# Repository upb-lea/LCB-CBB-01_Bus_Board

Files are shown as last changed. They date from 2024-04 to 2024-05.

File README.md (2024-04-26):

# Bus board LCB-CBB-01 for the LEA control board

This is the dock extension board for the LEA control board LCB-CCB-01. Please refer to the [LCB-CCB-01 repository](https://github.com/upb-lea/LCB-CCB-01_LEA_Control_Board) for a PCB and project overview.

Note, that you also need to install the `LEA KiCad Library` to view this PCB in this repository. To do this, follow the instructions mentioned [here](https://github.com/upb-lea/LCB-CCB-01_LEA_Control_Board/blob/main/README.md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).

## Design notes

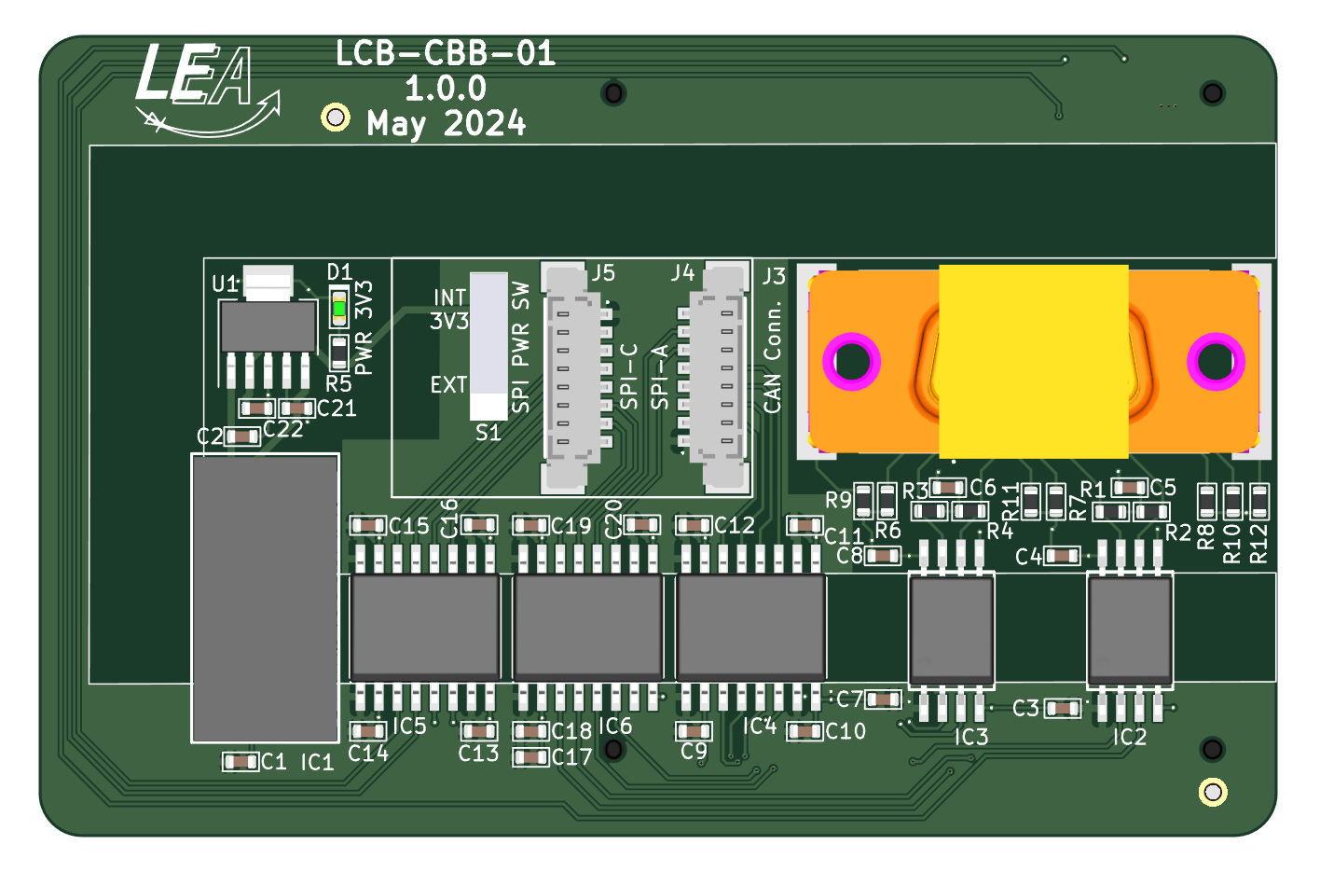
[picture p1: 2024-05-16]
LCB-CBB-01/LCB-CBB-01.png

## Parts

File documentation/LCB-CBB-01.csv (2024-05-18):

Source: | /home/nikolasf/Dokumente/01_git/70_PCBs/LCB-CBB-01_Bus_Board/LCB-CBB-01/LCB-CBB-01.kicad_sch
Date: | 2024-05-18T19:11:30+0200
Tool: | Eeschema 8.0.2
Generator: | /usr/share/kicad/plugins/bom_csv_grouped_by_value.py
Component Count: | 50
Collated Components:
Item | Qty | Reference(s) | Value | LibPart | Footprint | Datasheet | DNP | Datasheet | Description | Footprint | Manufacturer | Mfr. No | Mouser No | Sim.Enable | manf# | mouser#
1 | 2 | ACCESSORY1, ACCESSORY2 | ACCESSORY_BusBoard_SPI_Cable | LEA_SymbolLibrary:ACCESSORY_BusBoard_SPI_Cable |  | https://www.molex.com/en-us/products/part-detail/151340805 |  | https://www.molex.com/en-us/products/part-detail/151340805 |  |  | Molex |  |  |  | 15134-0805 | 538-15134-0805
2 | 12 | C1, C2, C3, C4, C7, C8, C10, C11, C14, C15, C18, C19 | 100n | LEA_SymbolLibrary:C_0603_100n_X5R_10P__50V | LEA_FootprintLibrary:C_0603 |  |  |  | Capacitor 0603 | LEA_FootprintLibrary:C_0603 | TDK |  |  |  | C1608X5R1H104K | 810-C1608X5R1H104K
3 | 2 | C5, C6 | 47n | LEA_SymbolLibrary:C_0603__47n_X7R_10P__50V | LEA_FootprintLibrary:C_0603 | https://www.mouser.de/datasheet/2/281/1/GCM188R71H473KA55_01A-3144223.pdf |  | https://www.mouser.de/datasheet/2/281/1/GCM188R71H473KA55_01A-3144223.pdf | Capacitor 0603 | LEA_FootprintLibrary:C_0603 | murata |  |  |  | GCM188R71H473K55D | 81-GCM188R71H473K55D
4 | 6 | C9, C12, C13, C16, C17, C20 | 2u2 | LEA_SymbolLibrary:C_0603__2u2_X5R_10P__35V | LEA_FootprintLibrary:C_0603 |  |  |  | Capacitor 0603 | LEA_FootprintLibrary:C_0603 | TDK |  |  |  | C1608X5R1V225K | 810-C1608X5R1V225K
5 | 1 | C21 | 10n | LEA_SymbolLibrary:C_0603__10n_X7R_10P__50V | LEA_FootprintLibrary:C_0603 |  |  |  | Capacitor 0603 | LEA_FootprintLibrary:C_0603 | TDK |  |  |  | CGA3E2X7R1H103K | 810-CGA3E2X7R1H103K
6 | 1 | C22 | 10u | LEA_SymbolLibrary:C_0603__10u_X5R_10P__25V | LEA_FootprintLibrary:C_0603 |  |  |  | Capacitor 0603 | LEA_FootprintLibrary:C_0603 | Murata |  |  |  | GRM188R61E106KA3D | 81-GRM188R61E106KA3D
7 | 1 | D1 | 2mA | LEA_SymbolLibrary:LED_0603_G_2mA_APTD1608LCGCK | LEA_FootprintLibrary:LED_0603_G | https://www.mouser.de/datasheet/2/216/APTD1608LCGCK-1102124.pdf |  | https://www.mouser.de/datasheet/2/216/APTD1608LCGCK-1102124.pdf | LED 0603, Green, If 2mA, Vf 1.9V | LEA_FootprintLibrary:LED_0603_G | Kingbright |  |  |  | APTD1608LCGCK | 604-APTD1608LCGCK
8 | 1 | IC1 | MEJ2S0305SC | LEA_SymbolLibrary:DCDC_3V3_5V0_MEJ2S0305SC | LEA_FootprintLibrary:SIP-7_Murata_MEJ1S0305SC | https://eu.mouser.com/datasheet/2/281/1/kdc_mej2-2941219.pdf |  | https://eu.mouser.com/datasheet/2/281/1/kdc_mej2-2941219.pdf | Isolated DC-DC Converter. 3.3Vin, 5Vout, 2W | LEA_FootprintLibrary:SIP-7_Murata_MEJ1S0305SC | Murata |  |  |  | MEJ2S0305SC | 580-MEJ2S0305SC
9 | 2 | IC2, IC3 | ISO1042QDWVRQ1 | LEA_SymbolLibrary:ISO_ISO1042QDWVRQ1 | LEA_FootprintLibrary:SOIC127P1150X280-8N | http://www.ti.com/lit/gpn/ISO1042-Q1 |  | http://www.ti.com/lit/gpn/ISO1042-Q1 | Isolated CAN transceiver, Automotive, 70-V bus fault protection and flexible data rate | LEA_FootprintLibrary:SOIC127P1150X280-8N | Texas Instruments |  |  |  | ISO1042QDWVRQ1 | 595-ISO1042QDWVRQ1
10 | 2 | IC4, IC5 | ISO7741FQDWQ1 | LEA_SymbolLibrary:ISO_ISO7741FQDWQ1 | LEA_FootprintLibrary:SOIC127P1030X265-16N | http://www.ti.com/lit/gpn/iso7741-q1 |  | http://www.ti.com/lit/gpn/iso7741-q1 | Automotive, High Speed, Robust EMC Quad-Channel Digital Isolators | LEA_FootprintLibrary:SOIC127P1030X265-16N | Texas Instruments |  |  |  | ISO7741FQDWQ1 | 595-ISO7741FQDWQ1
11 | 1 | IC6 | ISO_ISO7740FQDWQ1 | LEA_SymbolLibrary:ISO_ISO7740FQDWQ1 | LEA_FootprintLibrary:SOIC127P1030X265-16N | https://www.ti.com/lit/ds/symlink/iso7741-q1.pdf?ts=1637972753620 |  | https://www.ti.com/lit/ds/symlink/iso7741-q1.pdf?ts=1637972753620 | ISO774x-Q1 Automotive, High-Speed, Reinforced Quad-Channel Digital Isolators | LEA_FootprintLibrary:SOIC127P1030X265-16N | Texas Instruments |  |  |  | ISO7740FQDWQ1 | 595-ISO7740FQDWQ1
12 | 2 | J1, J2 | ERM5-075-05.0-L-DV-K-TR | LEA_SymbolLibrary:Conn_ERM5-075-05.0-L-DV-K-TR | LEA_FootprintLibrary:ERM5-075-05.0-L-DV | https://suddendocs.samtec.com/prints/erm5-xxx-xx.x-dv-xx-tr-footprint.pdf |  | https://suddendocs.samtec.com/prints/erm5-xxx-xx.x-dv-xx-tr-footprint.pdf | Board to Board & Mezzanine Connectors 0.50 mm Edge Rate Rugged High Speed Terminal | LEA_FootprintLibrary:ERM5-075-05.0-L-DV | Samtec | ERM5-075-05.0-L-DV-K-TR | 200-ERM5075050LDVKTR | 0 | ERM5-075-05.0-L-DV-K-TR | 200-ERM5075050LDVKTR
13 | 1 | J3 | 09551156612741 | LEA_SymbolLibrary:Conn_sub-D_09551156612741 | LEA_FootprintLibrary:Conn_Sub-D_09551156612741 | https://b2b.harting.com/files/download/PRD/PDF_TS/0955115X61X_100236642DRW001C.pdf |  | https://b2b.harting.com/files/download/PRD/PDF_TS/0955115X61X_100236642DRW001C.pdf | D-Sub SMD 9pin straight female | LEA_FootprintLibrary:Conn_Sub-D_09551156612741 | HARTING |  |  |  | 09551156612741 | 617-09551156612741
14 | 2 | J4, J5 | 53398-0871 | LEA_SymbolLibrary:Conn_molex_533980871 | LEA_FootprintLibrary:Conn_Molex_533980871 | http://www.molex.com/webdocs/datasheets/pdf/en-us/0533980871_PCB_HEADERS.pdf |  | http://www.molex.com/webdocs/datasheets/pdf/en-us/0533980871_PCB_HEADERS.pdf | 8 Pin Male, straight, 1.25mm pitch | LEA_FootprintLibrary:Conn_Molex_533980871 | Molex |  |  |  | 53398-0871 | 538-53398-0871
15 | 4 | R1, R2, R3, R4 | 60R4 | LEA_SymbolLibrary:R_0603_60R4_THICK_0.5P_150V | LEA_FootprintLibrary:R_0603 | https://www.mouser.de/datasheet/2/348/ROHM_S_A0011075102_1-2563252.pdf |  | https://www.mouser.de/datasheet/2/348/ROHM_S_A0011075102_1-2563252.pdf | Resistor 0603 | LEA_FootprintLibrary:R_0603 | ROHM Semiconductor |  |  |  | ESR03EZPD60R4 | 755-ESR03EZPD60R4
16 | 1 | R5 | 680R | LEA_SymbolLibrary:R_0603_680R_THICK__1P__75V | LEA_FootprintLibrary:R_0603 |  |  |  | Resistor 0603 | LEA_FootprintLibrary:R_0603 | Vishay |  |  |  | CRCW0603680RFKEAC | 71-CRCW0603680RFKEAC
17 | 7 | R6, R7, R8, R9, R10, R11, R12 | 0R0 | LEA_SymbolLibrary:R_0603__0R0_THICK__1P__75V | LEA_FootprintLibrary:R_0603 |  |  |  | Resistor 0603 | LEA_FootprintLibrary:R_0603 | Vishay |  |  |  | CRCW06030000Z0EAC | 71-CRCW06030000Z0EAC
18 | 1 | S1 | SW_09.03290.01 | LEA_SymbolLibrary:SW_09.03290.01 | LEA_FootprintLibrary:090329001 | https://www.mouser.co.uk/datasheet/2/628/EAO_1K2%20data%20sheet-1216079.pdf |  | https://www.mouser.co.uk/datasheet/2/628/EAO_1K2%20data%20sheet-1216079.pdf | Slide Switches SPDT, ON-ON, slide, Through Hole, 500 mA @ 24 V DC | LEA_FootprintLibrary:090329001 | EAO |  |  |  | 09.03290.01 | 123-09.03290.01
19 | 1 | U1 | TPS73733DCQ | LEA_SymbolLibrary:TPS73733DCQ | LEA_FootprintLibrary:SOT-223-6_TI | https://www.ti.com/lit/ds/symlink/tps737.pdf |  | https://www.ti.com/lit/ds/symlink/tps737.pdf |  | LEA_FootprintLibrary:SOT-223-6_TI | TI |  |  |  | TPS73733DCQG4 | 595-TPS73733DCQG4

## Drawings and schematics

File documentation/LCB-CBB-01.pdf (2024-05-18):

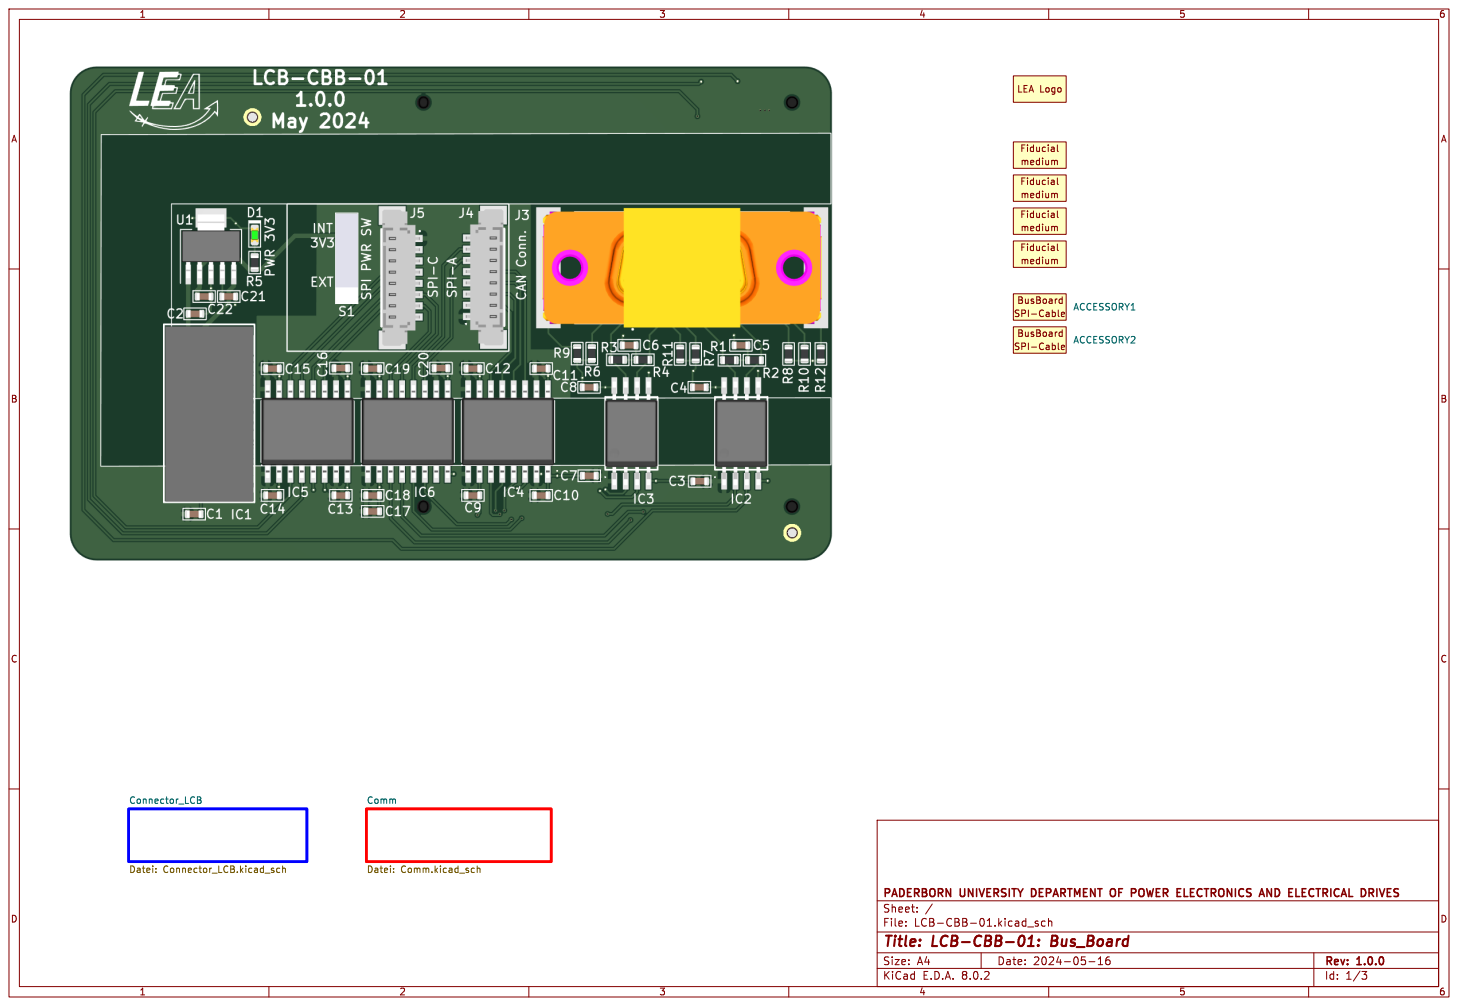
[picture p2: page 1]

LEA Logo Fiducial medium

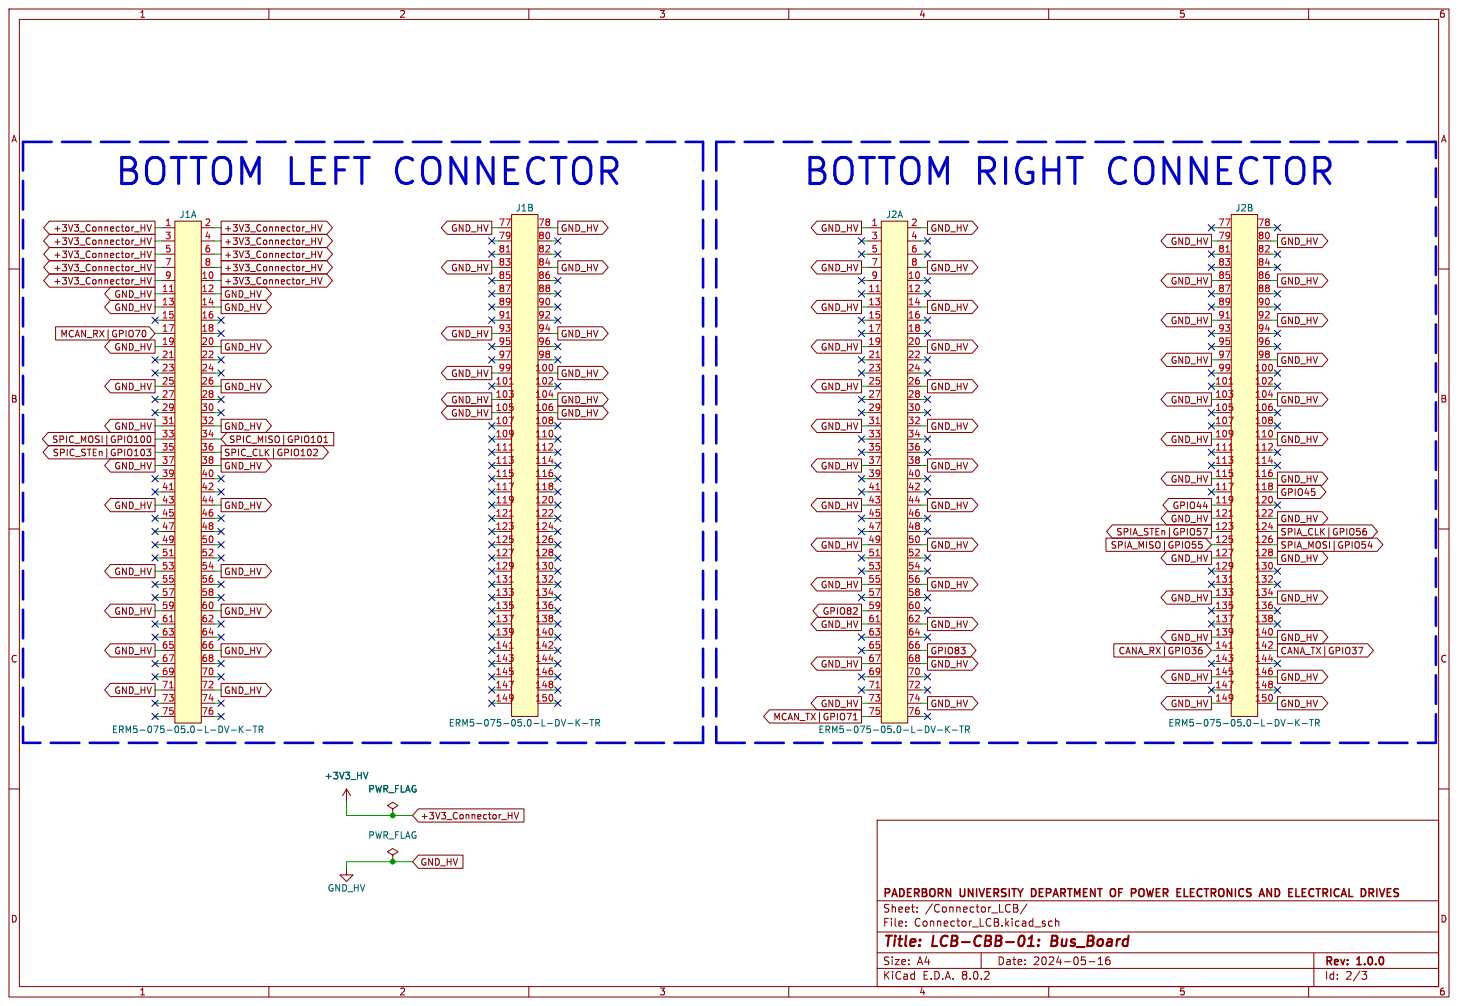
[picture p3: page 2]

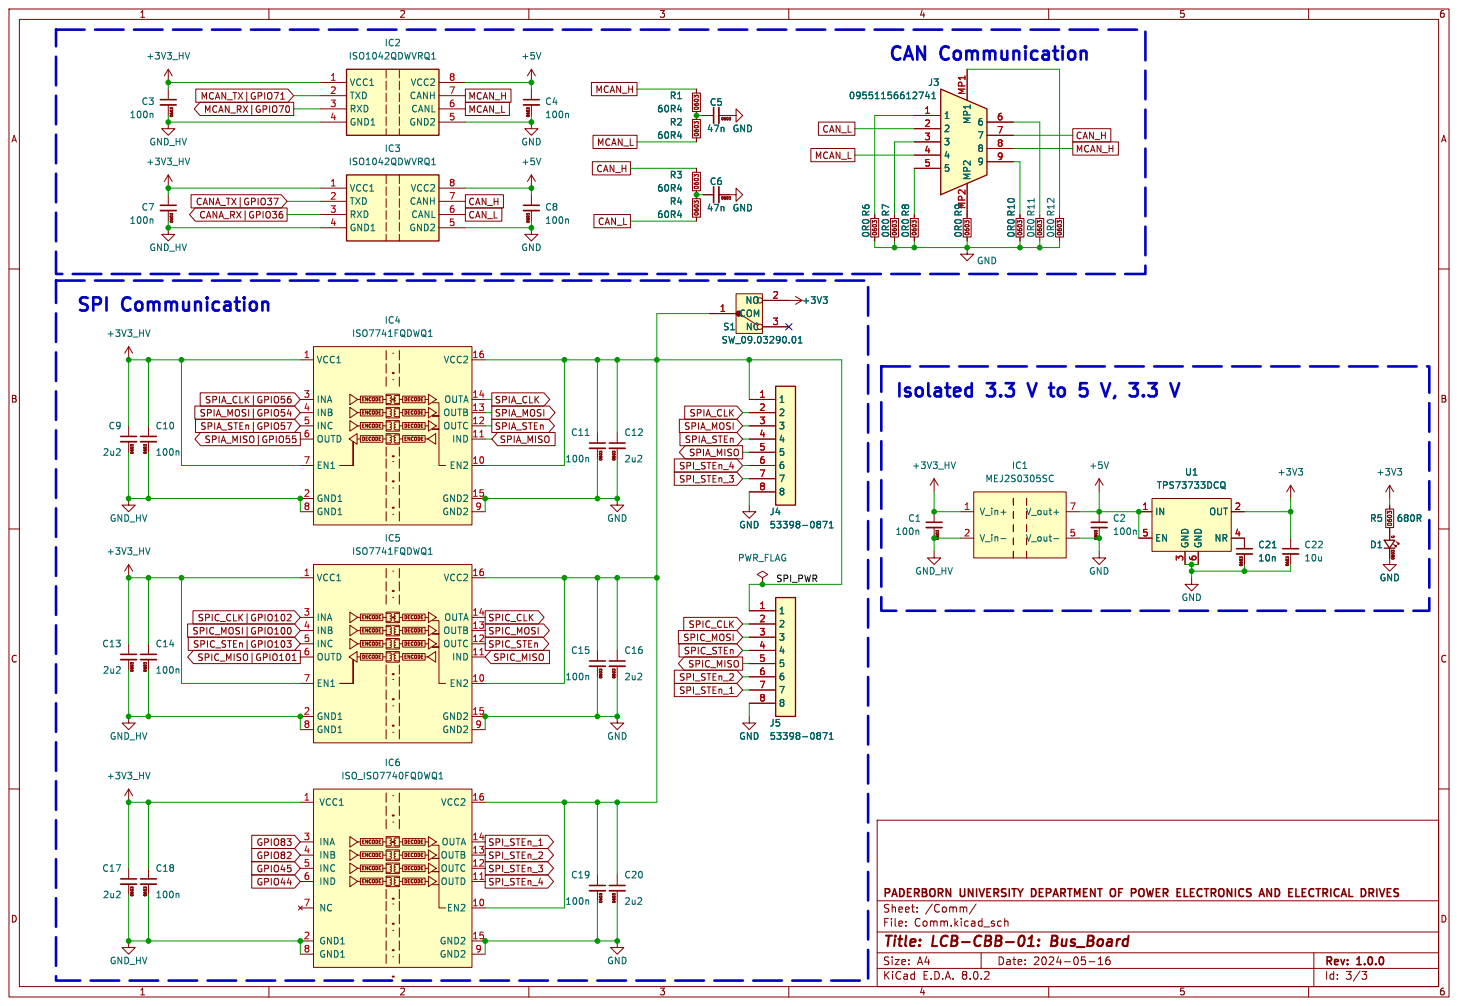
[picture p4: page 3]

IND 11 OUTC 12 OUTB 13 OUTA 14 GND2 15 VCC2 16 GND1 2

DECODE DECODE

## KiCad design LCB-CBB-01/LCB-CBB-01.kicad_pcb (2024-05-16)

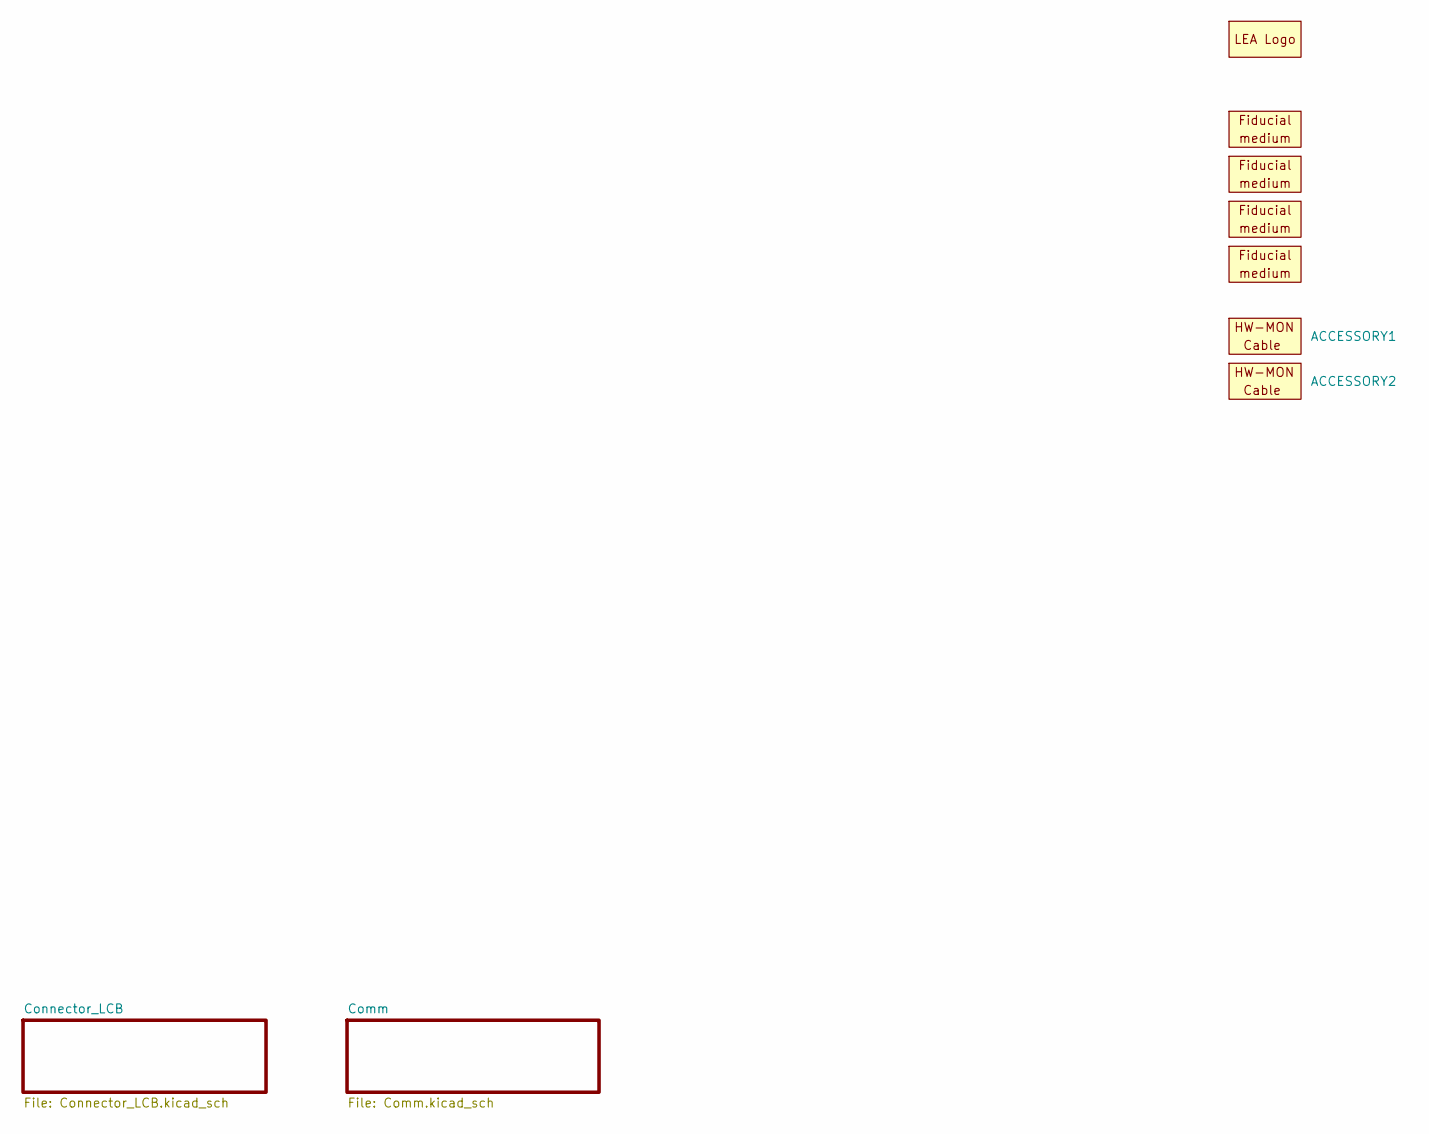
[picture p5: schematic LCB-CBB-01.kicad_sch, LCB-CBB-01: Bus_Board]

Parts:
ACCESSORY1, ACCESSORY2: ACCESSORY_BusBoard_SPI_Cable; mouser# 538-15134-0805
O1, O2, O3, O4: Fiducial_medium; Fiducials_medium
SYM1: SYM_LEA_Logo; SYM_lea_logo

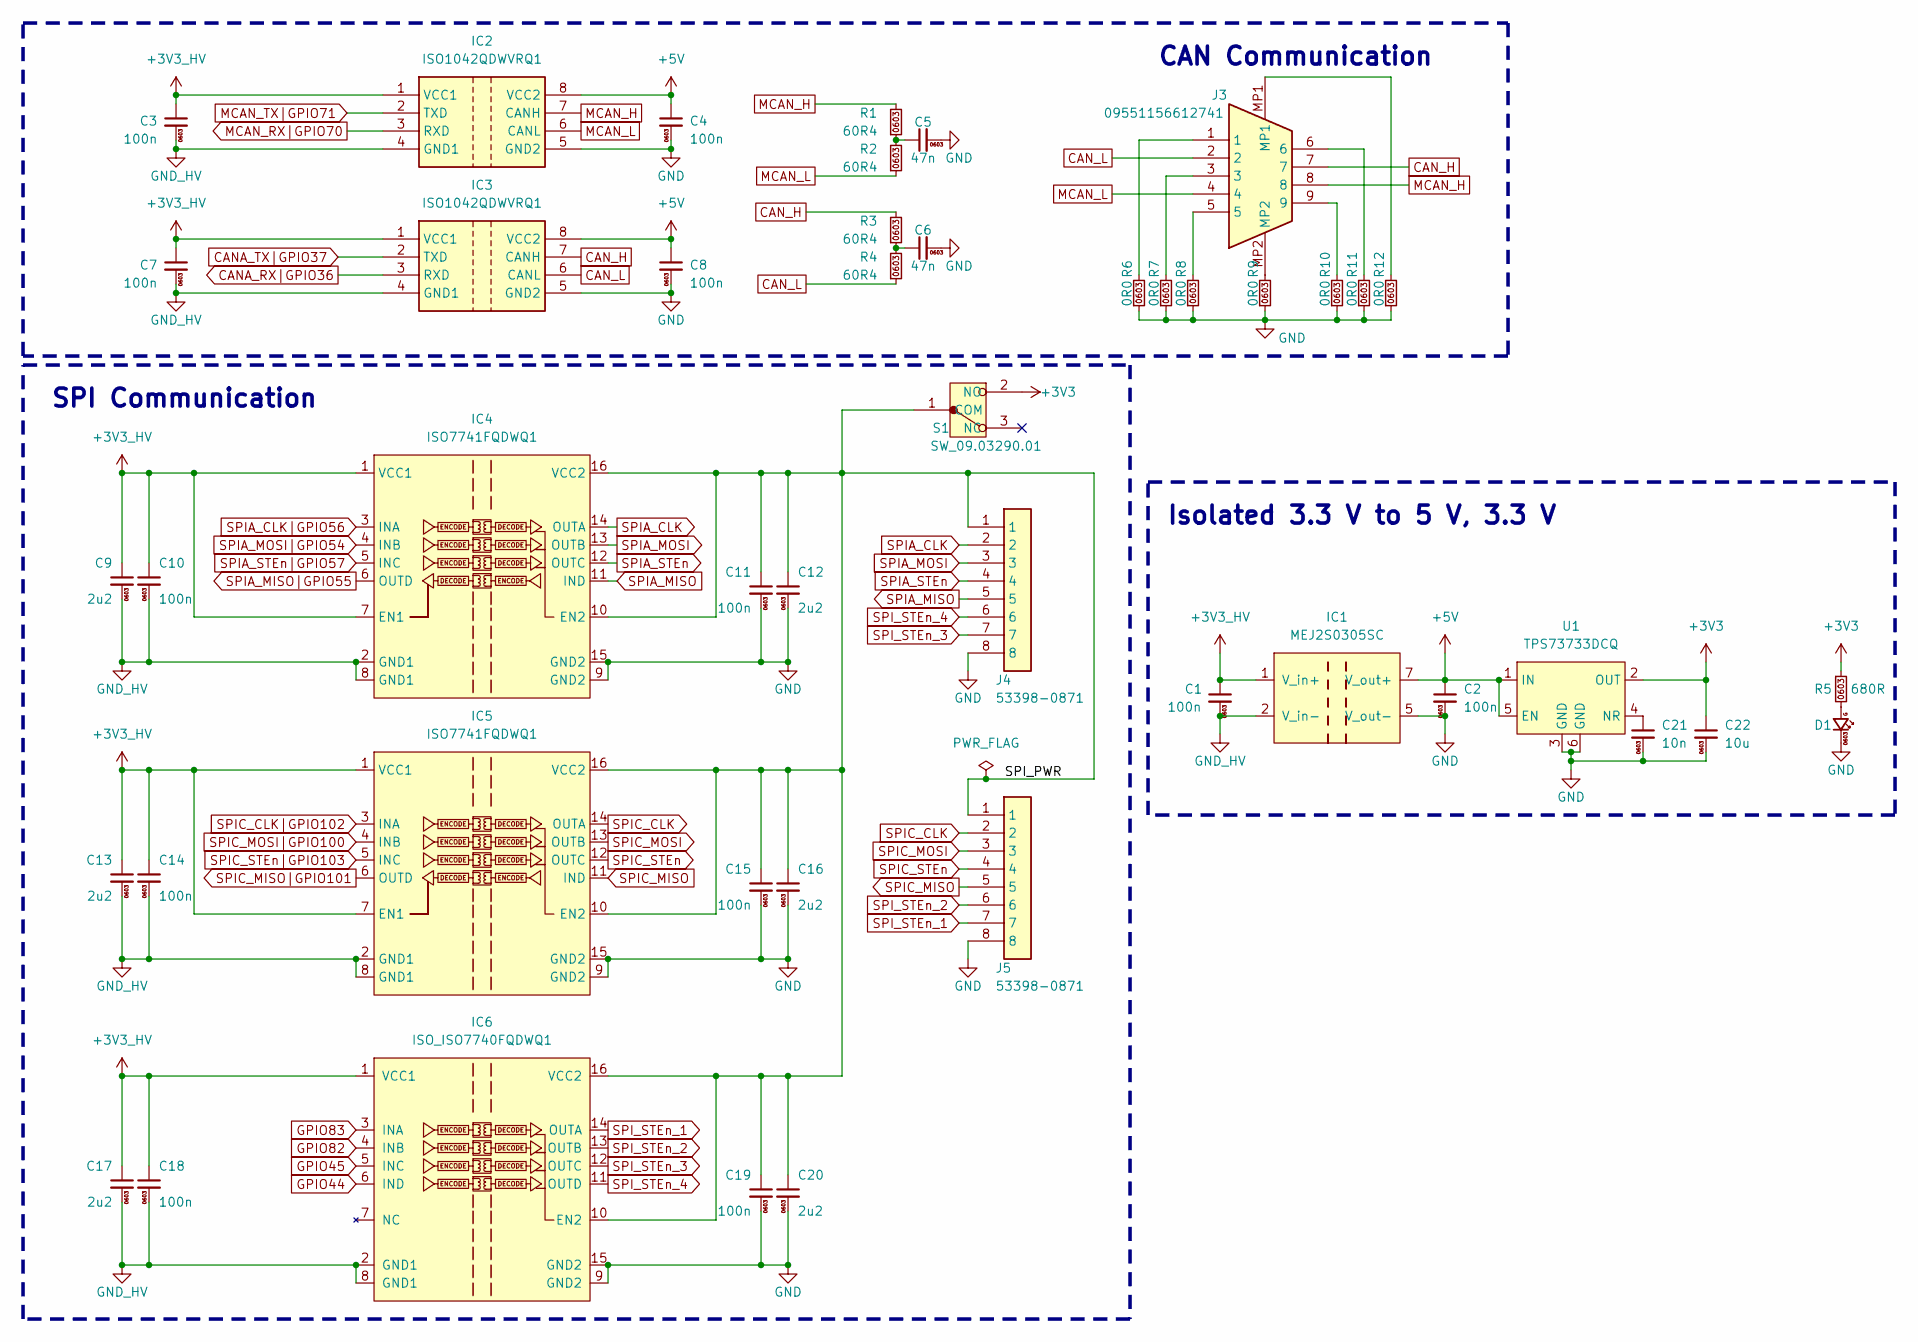
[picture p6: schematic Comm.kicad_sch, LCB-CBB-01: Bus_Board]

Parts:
C1, C2, C3, C4, C7, C8, C10, C11, C14, C15, C18, C19: 100n; C_0603; mouser# 810-C1608X5R1H104K
C5, C6: 47n; C_0603; mouser# 81-GCM188R71H473K55D
C9, C12, C13, C16, C17, C20: 2u2; C_0603; mouser# 810-C1608X5R1V225K
C21: 10n; C_0603; mouser# 810-CGA3E2X7R1H103K
C22: 10u; C_0603; mouser# 81-GRM188R61E106KA3D
D1: 2mA; LED_0603_G; mouser# 604-APTD1608LCGCK
IC1: MEJ2S0305SC; SIP-7_Murata_MEJ1S0305SC; mouser# 580-MEJ2S0305SC
IC2, IC3: ISO1042QDWVRQ1; SOIC127P1150X280-8N; mouser# 595-ISO1042QDWVRQ1
IC4, IC5: ISO7741FQDWQ1; SOIC127P1030X265-16N; mouser# 595-ISO7741FQDWQ1
IC6: ISO_ISO7740FQDWQ1; SOIC127P1030X265-16N; mouser# 595-ISO7740FQDWQ1
J3: 09551156612741; Conn_Sub-D_09551156612741; mouser# 617-09551156612741
J4, J5: 53398-0871; Conn_Molex_533980871; mouser# 538-53398-0871
R1, R2, R3, R4: 60R4; R_0603; mouser# 755-ESR03EZPD60R4
R5: 680R; R_0603; mouser# 71-CRCW0603680RFKEAC
R6, R7, R8, R9, R10, R11, R12: 0R0; R_0603; mouser# 71-CRCW06030000Z0EAC
S1: SW_09.03290.01; 090329001; mouser# 123-09.03290.01
U1: TPS73733DCQ; SOT-223-6_TI; mouser# 595-TPS73733DCQG4

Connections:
+3V3: C22.1, R5.1, S1.2 (NO), U1.2 (OUT)
+3V3_Connector_HV: C1.1, C3.1, C7.1, C9.1, C10.1, C13.1, C14.1, C17.1, C18.1, IC1.1 (V_in+), IC2.1 (VCC1), IC3.1 (VCC1), IC4.1 (VCC1), IC4.7 (EN1), IC5.1 (VCC1), IC5.7 (EN1), IC6.1 (VCC1); also elsewhere on the board
+5V: C2.1, C4.1, C8.1, IC1.7 (V_out+), IC2.8 (VCC2), IC3.8 (VCC2), U1.1 (IN), U1.5 (EN)
/Comm/SPI_PWR: C11.1, C12.1, C15.1, C16.1, C19.1, C20.1, IC4.10 (EN2), IC4.16 (VCC2), IC5.10 (EN2), IC5.16 (VCC2), IC6.10 (EN2), IC6.16 (VCC2), J4.1, J5.1, S1.1 (COM)
CANA_RX|GPIO36: IC3.3 (RXD); also elsewhere on the board
CANA_TX|GPIO37: IC3.2 (TXD); also elsewhere on the board
CAN_H: IC3.7 (CANH), J3.7, R3.2
CAN_L: IC3.6 (CANL), J3.2, R4.1
GND: C2.2, C4.2, C5.2, C6.2, C8.2, C11.2, C12.2, C15.2, C16.2, C19.2, C20.2, C21.2, C22.2, D1.C, IC1.5 (V_out-), IC2.5 (GND2), IC3.5 (GND2), IC4.9 (GND2), IC4.15 (GND2), IC5.9 (GND2), IC5.15 (GND2), IC6.9 (GND2), IC6.15 (GND2), J4.8, J5.8, R6.1, R7.1, R8.1, R9.1, R10.1, R11.1, R12.1, U1.3 (GND), U1.6 (GND)
GND_HV: C1.2, C3.2, C7.2, C9.2, C10.2, C13.2, C14.2, C17.2, C18.2, IC1.2 (V_in-), IC2.4 (GND1), IC3.4 (GND1), IC4.2 (GND1), IC4.8 (GND1), IC5.2 (GND1), IC5.8 (GND1), IC6.2 (GND1), IC6.8 (GND1); also elsewhere on the board
GPIO44: IC6.6 (IND); also elsewhere on the board
GPIO45: IC6.5 (INC); also elsewhere on the board
GPIO82: IC6.4 (INB); also elsewhere on the board
GPIO83: IC6.3 (INA); also elsewhere on the board
MCAN_H: IC2.7 (CANH), J3.8, R1.2
MCAN_L: IC2.6 (CANL), J3.4, R2.1
MCAN_RX|GPIO70: IC2.3 (RXD); also elsewhere on the board
MCAN_TX|GPIO71: IC2.2 (TXD); also elsewhere on the board
unnamed: C5.1, R1.1, R2.2
unnamed: C6.1, R3.1, R4.2
unnamed: D1.A, R5.2
unnamed: J3.1, R6.2
unnamed: J3.3, R7.2
unnamed: J3.5, R8.2
unnamed: J3.6, R11.2
unnamed: J3.9, R10.2
unnamed: J3.MP1, R12.2
unnamed: J3.MP2, R9.2
unnamed: C21.1, U1.4 (NR)
SPIA_CLK: IC4.14 (OUTA), J4.2
SPIA_CLK|GPIO56: IC4.3 (INA); also elsewhere on the board
SPIA_MISO: IC4.11 (IND), J4.5
SPIA_MISO|GPIO55: IC4.6 (OUTD); also elsewhere on the board
SPIA_MOSI: IC4.13 (OUTB), J4.3
SPIA_MOSI|GPIO54: IC4.4 (INB); also elsewhere on the board
SPIA_STEn: IC4.12 (OUTC), J4.4
SPIA_STEn|GPIO57: IC4.5 (INC); also elsewhere on the board
SPIC_CLK: IC5.14 (OUTA), J5.2
SPIC_CLK|GPIO102: IC5.3 (INA); also elsewhere on the board
SPIC_MISO: IC5.11 (IND), J5.5
SPIC_MISO|GPIO101: IC5.6 (OUTD); also elsewhere on the board
SPIC_MOSI: IC5.13 (OUTB), J5.3
SPIC_MOSI|GPIO100: IC5.4 (INB); also elsewhere on the board
SPIC_STEn: IC5.12 (OUTC), J5.4
SPIC_STEn|GPIO103: IC5.5 (INC); also elsewhere on the board
SPI_STEn_1: IC6.14 (OUTA), J5.7
SPI_STEn_2: IC6.13 (OUTB), J5.6
SPI_STEn_3: IC6.12 (OUTC), J4.7
SPI_STEn_4: IC6.11 (OUTD), J4.6

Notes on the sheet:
CAN Communication
SPI Communication
Isolated 3.3 V to 5 V, 3.3 V

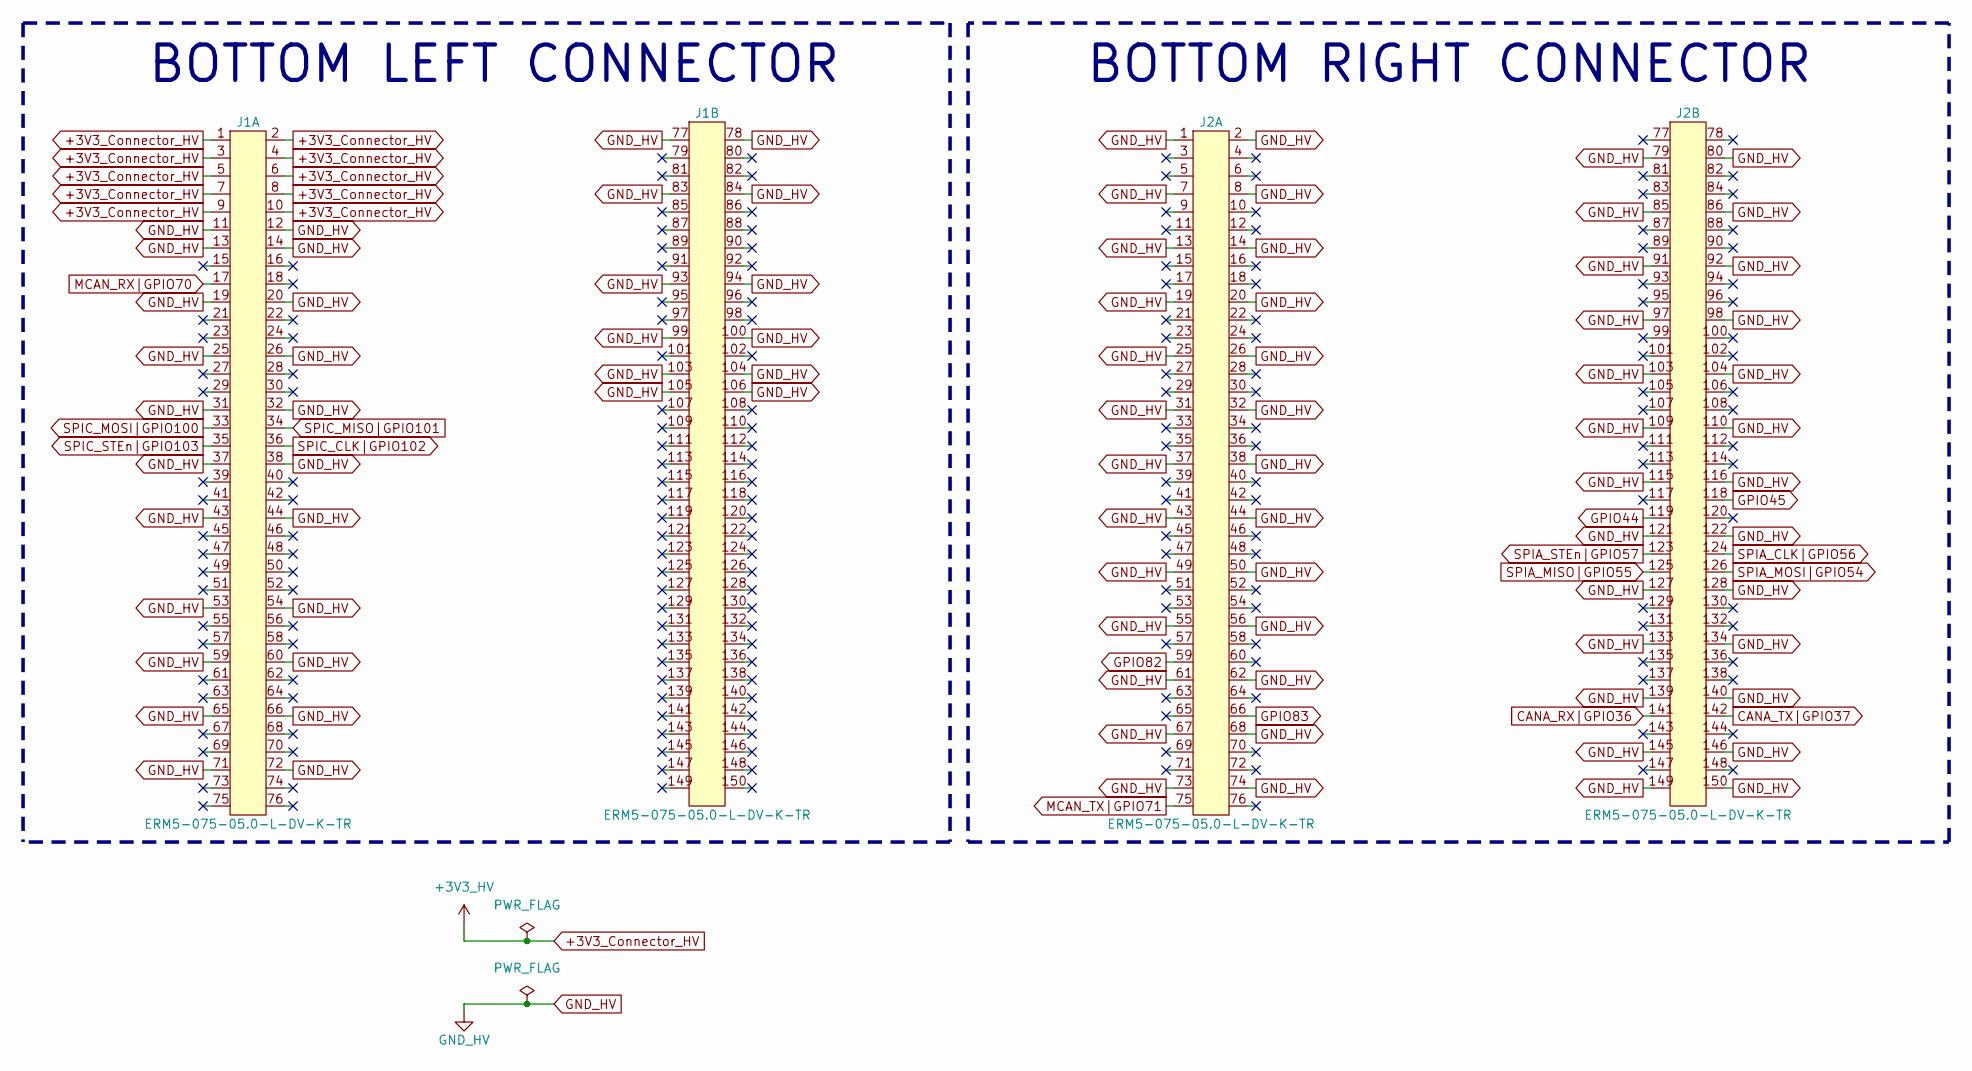
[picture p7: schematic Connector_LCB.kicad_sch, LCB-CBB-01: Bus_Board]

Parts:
J1, J2: ERM5-075-05.0-L-DV-K-TR; ERM5-075-05.0-L-DV; mouser# 200-ERM5075050LDVKTR; Mouser No 200-ERM5075050LDVKTR

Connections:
+3V3_Connector_HV: J1.1, J1.2, J1.3, J1.4, J1.5, J1.6, J1.7, J1.8, J1.9, J1.10; also elsewhere on the board
CANA_RX|GPIO36: J2.141; also elsewhere on the board
CANA_TX|GPIO37: J2.142; also elsewhere on the board
GND_HV: J1.11, J1.12, J1.13, J1.14, J1.19, J1.20, J1.25, J1.26, J1.31, J1.32, J1.37, J1.38, J1.43, J1.44, J1.53, J1.54, J1.59, J1.60, J1.65, J1.66, J1.71, J1.72, J1.77, J1.78, J1.83, J1.84, J1.93, J1.94, J1.99, J1.100, J1.103, J1.104, J1.105, J1.106, J2.1, J2.2, J2.7, J2.8, J2.13, J2.14, J2.19, J2.20, J2.25, J2.26, J2.31, J2.32, J2.37, J2.38, J2.43, J2.44, J2.49, J2.50, J2.55, J2.56, J2.61, J2.62, J2.67, J2.68, J2.73, J2.74, J2.79, J2.80, J2.85, J2.86, J2.91, J2.92, J2.97, J2.98, J2.103, J2.104, J2.109, J2.110, J2.115, J2.116, J2.121, J2.122, J2.127, J2.128, J2.133, J2.134, J2.139, J2.140, J2.145, J2.146, J2.149, J2.150; also elsewhere on the board
GPIO44: J2.119; also elsewhere on the board
GPIO45: J2.118; also elsewhere on the board
GPIO82: J2.59; also elsewhere on the board
GPIO83: J2.66; also elsewhere on the board
MCAN_RX|GPIO70: J1.17; also elsewhere on the board
MCAN_TX|GPIO71: J2.75; also elsewhere on the board
SPIA_CLK|GPIO56: J2.124; also elsewhere on the board
SPIA_MISO|GPIO55: J2.125; also elsewhere on the board
SPIA_MOSI|GPIO54: J2.126; also elsewhere on the board
SPIA_STEn|GPIO57: J2.123; also elsewhere on the board
SPIC_CLK|GPIO102: J1.36; also elsewhere on the board
SPIC_MISO|GPIO101: J1.34; also elsewhere on the board
SPIC_MOSI|GPIO100: J1.33; also elsewhere on the board
SPIC_STEn|GPIO103: J1.35; also elsewhere on the board

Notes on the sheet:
BOTTOM LEFT CONNECTOR
BOTTOM RIGHT CONNECTOR

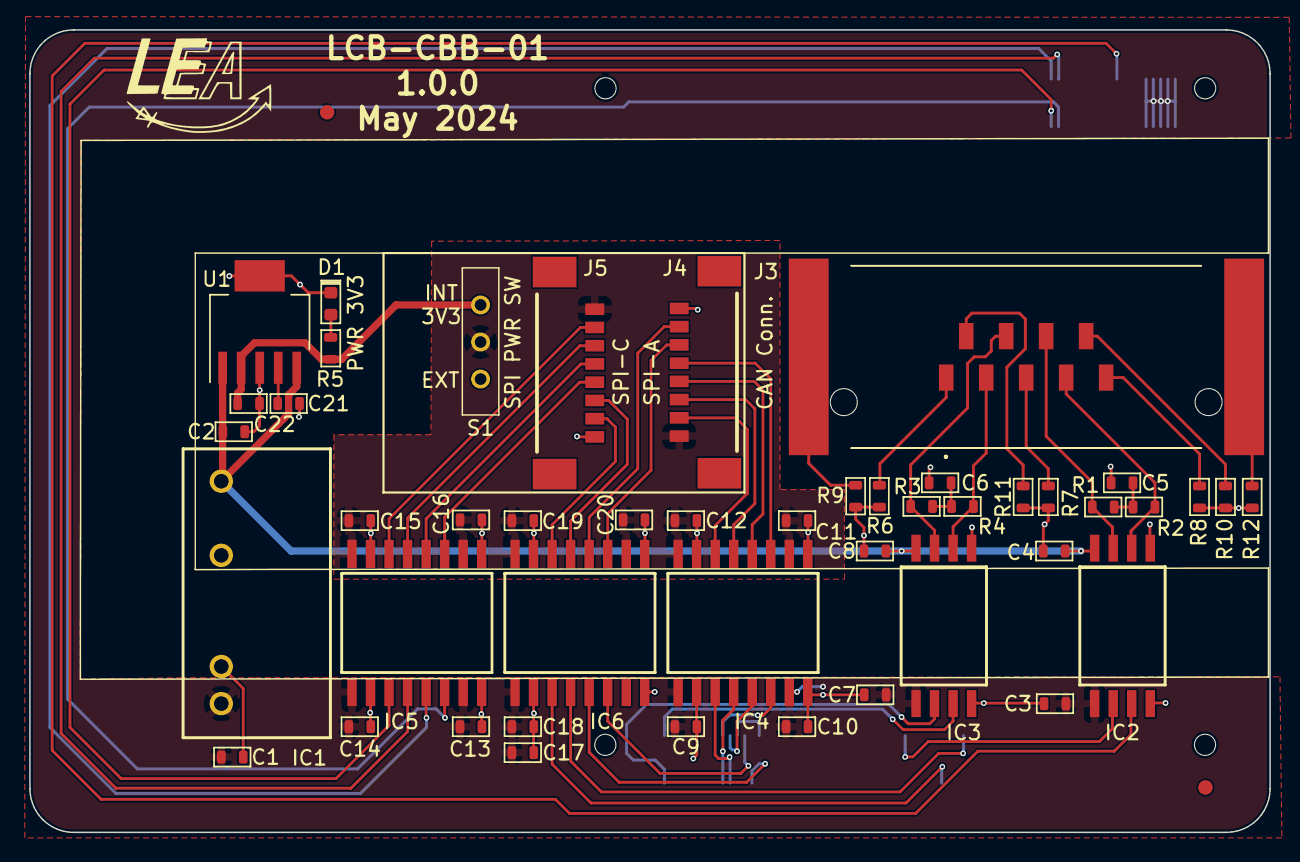
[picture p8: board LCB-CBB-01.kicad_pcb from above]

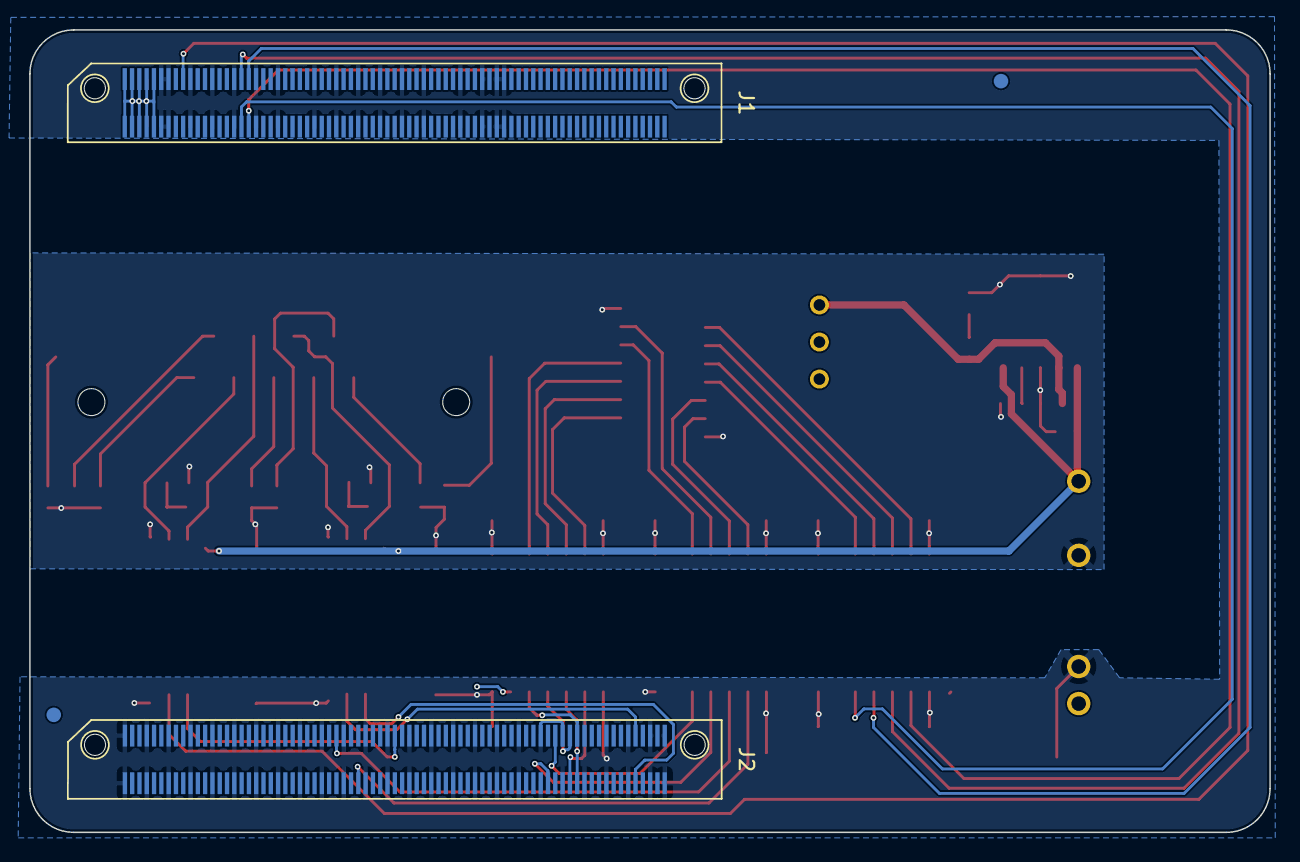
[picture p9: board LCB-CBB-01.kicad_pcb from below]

Board: 2 copper layers, 85.0 x 55.0 mm, 53 parts (4 on the bottom side), 49 nets.

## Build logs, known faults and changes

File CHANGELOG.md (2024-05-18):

# Changelog
All notable changes to this project will be documented in this file.

The format is based on [Keep a Changelog](https://keepachangelog.com/en/1.0.0/),
and this project adheres to [Semantic Versioning](https://semver.org/spec/v2.0.0.html).

## [Unreleased] - xxxx-xx-xx

## [1.0.0] - 2023-05-18
### Added
 * LCB-CBB-01 Control Bus Board initial release

[1.0.0]: https://github.com/upb-lea/LCB-CBB-01_Bus_Board/compare/1.0.0...1.0.0

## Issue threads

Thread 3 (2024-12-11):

Update Footprint of sub-D connector

gituser789, 2024-12-11:
The sub-D connector on the PCB itself has wrong outer pads (wrong size, wrong position).
This has already been fixed in the library, but must be updated in the pcb too.
This is a reminder to update and validate the sub-d connector footprint from the library.

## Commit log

2024-04-26 set up project structure
    [LCB-CBB-01.kicad_pcb, LCB-CBB-01.kicad_sch]
2024-05-16 update to kicad 8, subd connector update
    [Comm.kicad_sch, Connector_LCB.kicad_sch, LCB-CBB-01.kicad_pcb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]
2024-05-18 bump version to 1.0.0
    [Connector_LCB.kicad_sch, LCB-CBB-01.csv, LCB-CBB-01.kicad_sch]
